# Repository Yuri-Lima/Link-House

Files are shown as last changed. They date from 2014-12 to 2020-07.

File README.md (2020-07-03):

<!-- Headings --> <!-- Strong --> <!-- Italics --> <!-- Blockquote --> <!-- Links --> <!-- UL --> <!-- OL --> <!-- Images --> <!-- Code Blocks --> <!-- Tables --> 
<!-- Task Lists -->

> # Homefi AX

### The project started in 2014. This project had the intention to created access for home automation to find an of family income population.
The Homefi module was created to be easily installed by users with low knowledge in home electronics. The unique skills  required the user wasi the connection of wires for the system to be installed. The Homefi project was cancelled around at 2016 after the launch of the Chinese module called Sonoff. This module basically does the same service as Homefi AX. **Web site:** [sonoff](https://sonoff.tech/) 

> ### Hardware

1. ESP8266 2.4Ghz board from espressif;
1. Solid States Relays;
1. 100 16v SMD Capacitors;
1. Hi-Link Imput 240Vac to 5Vdc/3w as Power Suply;
1. BC 846 Transistor;</li>
1. DHT11 as Temperature Sensor;
1. Varistor and Inductor as protection of the circuit;
1. General conectors.

> ### Software

1. Eagle to PCB;
1. Arduino IDE;
1. [Onlinegerberviewer](https://onlinegerberviewer.azurewebsites.net/)

> ### Software Main Language Used
* The Arduino IDE supports the languages C and C++ using special rules of code structuring. 
  The Arduino IDE supplies a software library from the Wiring project, which provides many common input and output procedures

> ### Protoypes Images

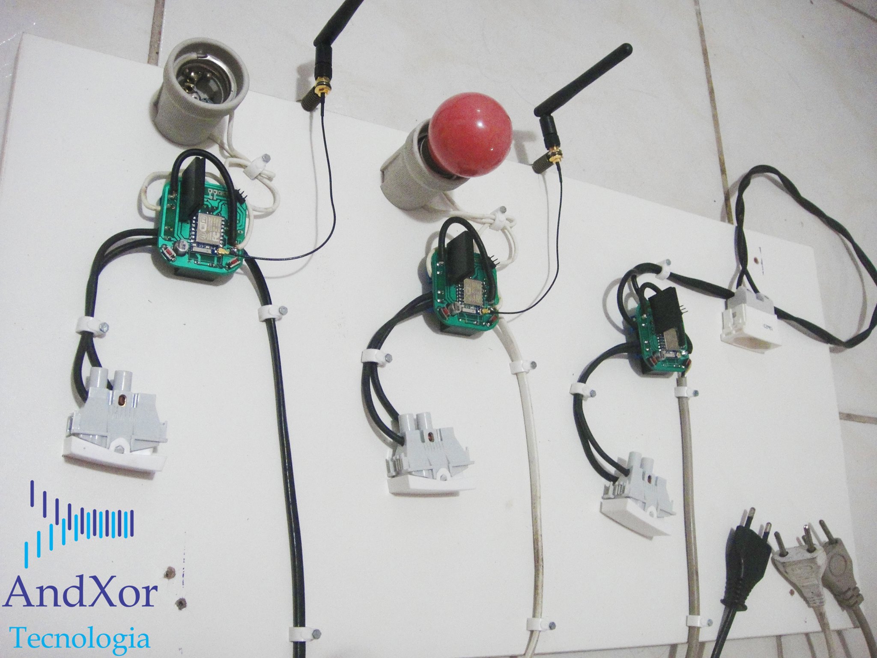
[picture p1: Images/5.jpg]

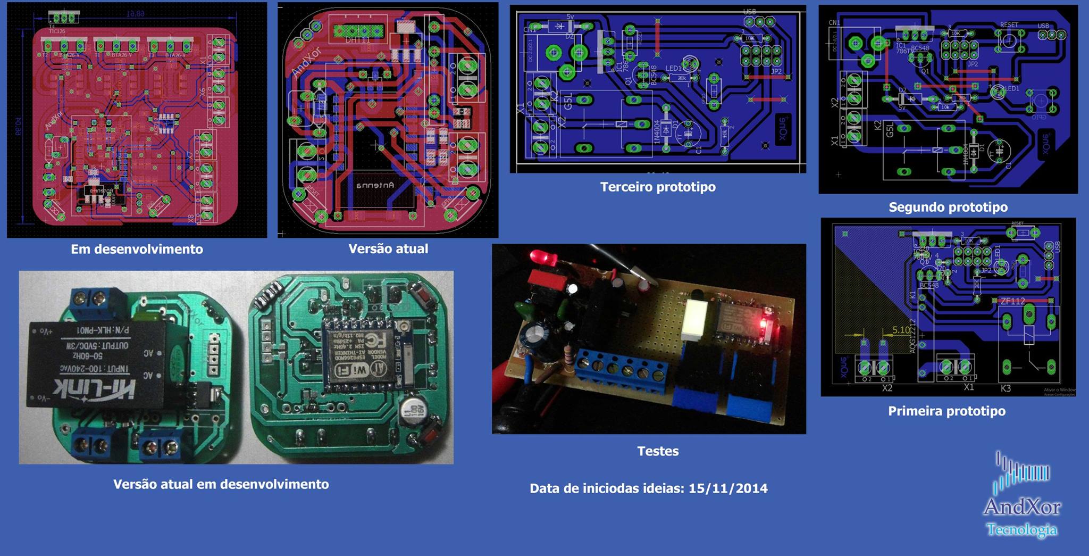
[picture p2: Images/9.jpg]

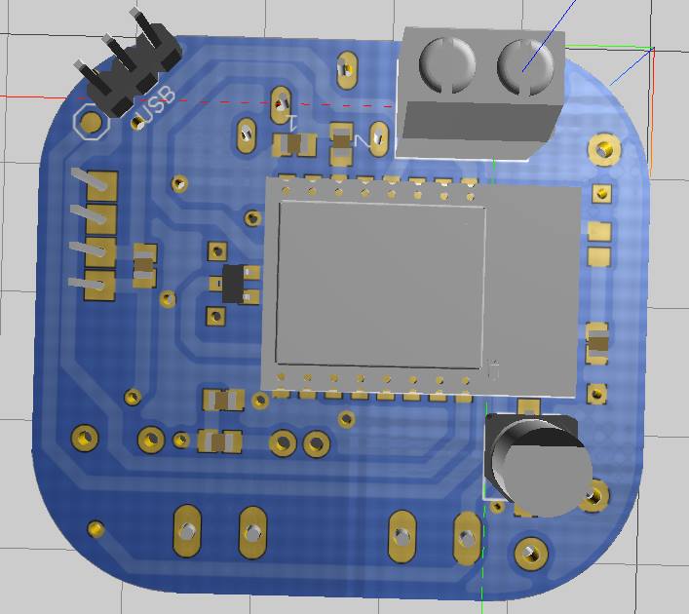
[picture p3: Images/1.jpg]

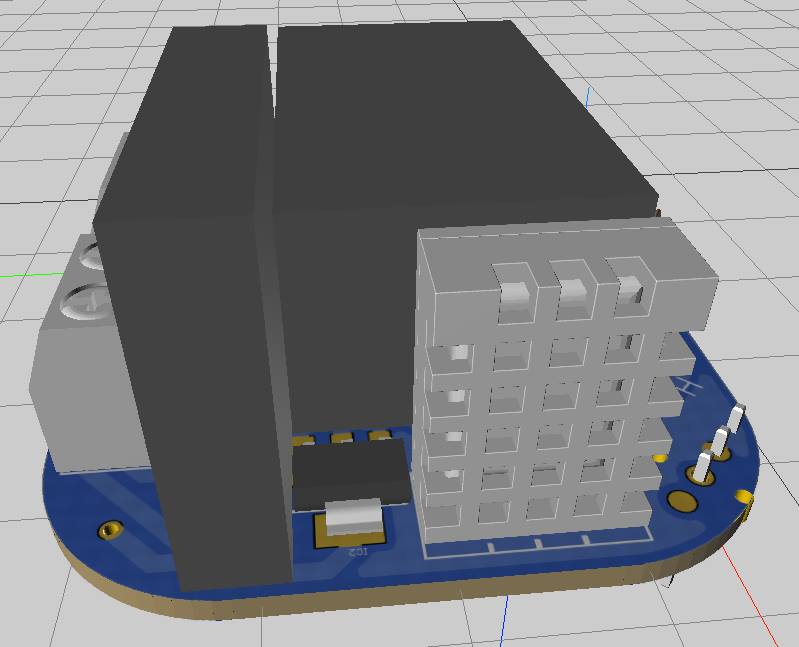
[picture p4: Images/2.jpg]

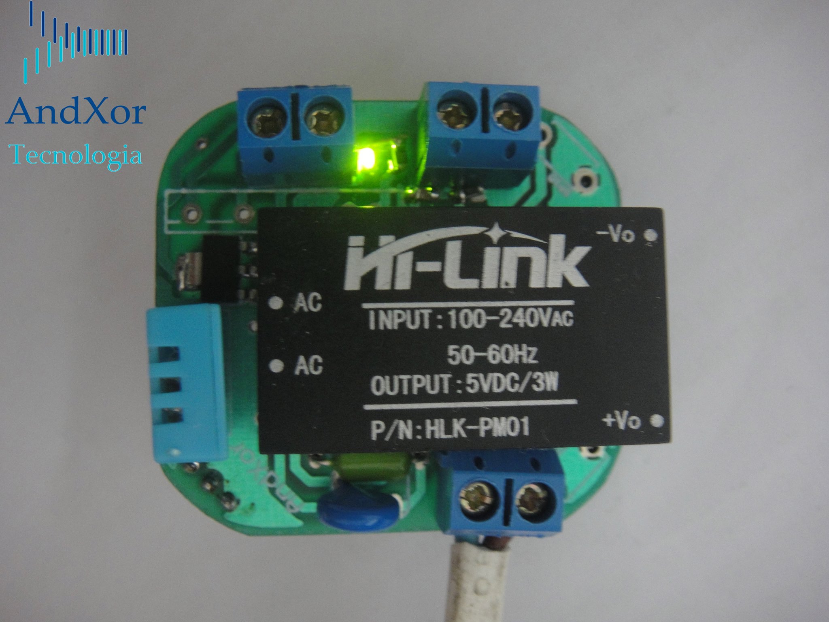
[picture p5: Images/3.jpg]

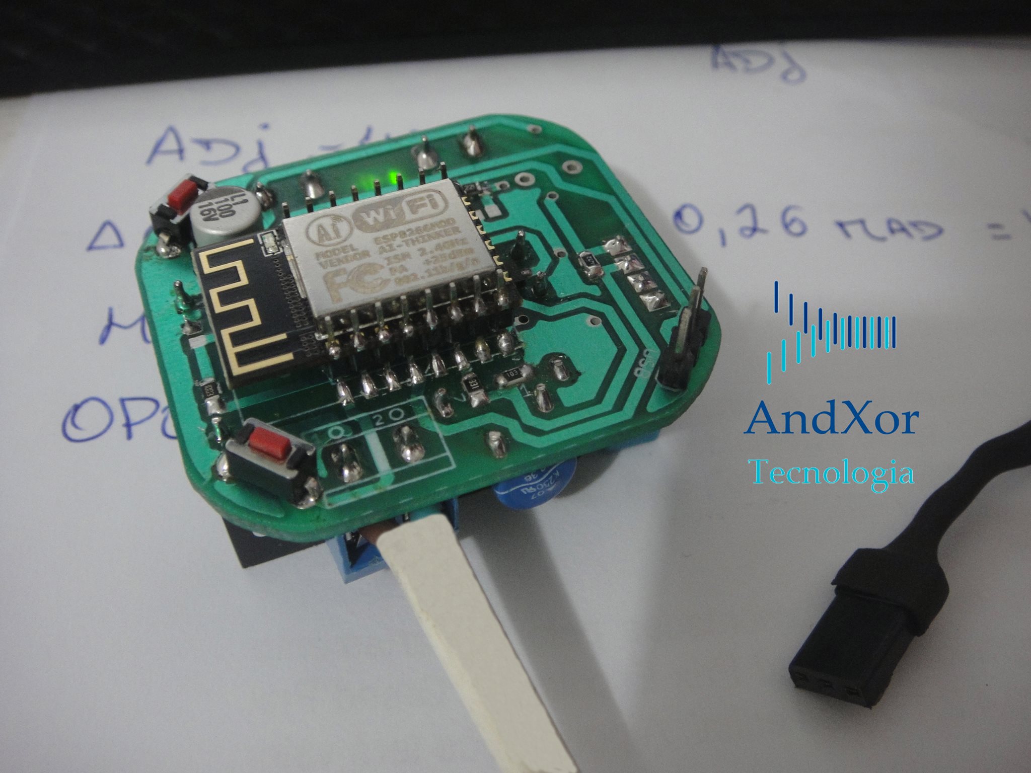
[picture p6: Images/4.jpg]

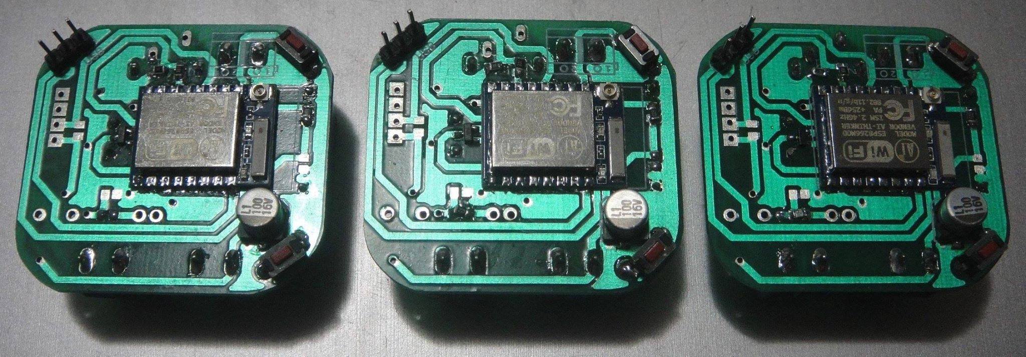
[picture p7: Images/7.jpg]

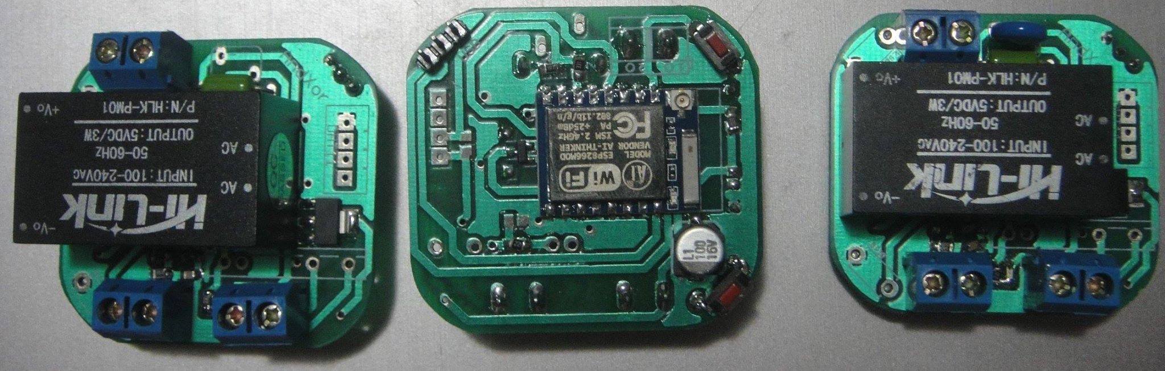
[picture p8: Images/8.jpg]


> ### Contact

> **Atention** If you go email me, please put as subject the name of the project, in this case: **(Homefi AX) Requests**

|  Name |  Email | Mobile  |
|---|---|---|
|  Yuri Lima | y.m.lima19@gmail.com  | +353 83 419.1605  |

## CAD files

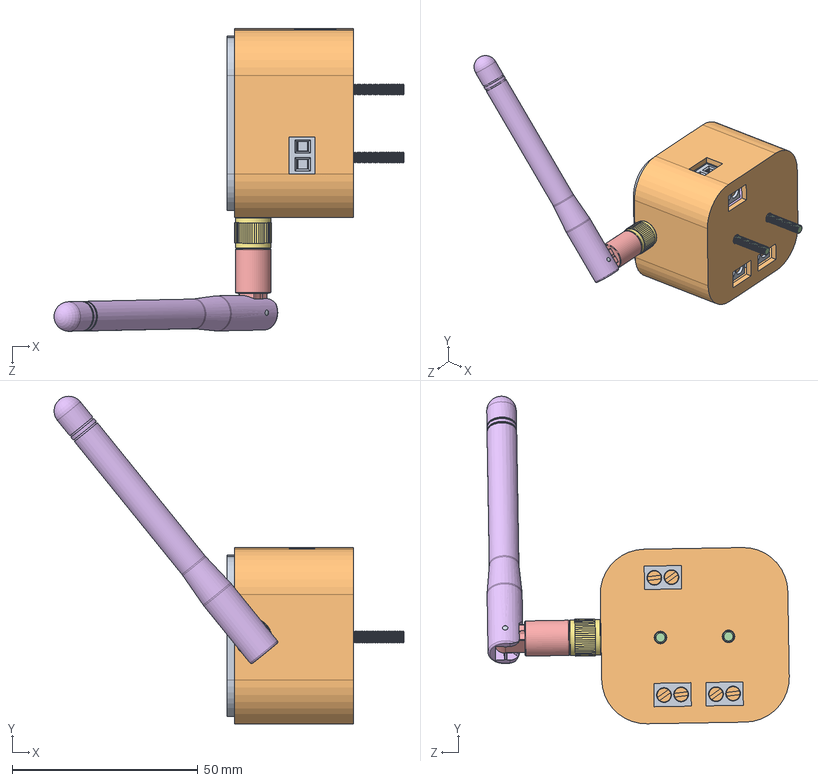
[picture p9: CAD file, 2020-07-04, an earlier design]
OLD Things/Case_Homefi/Montagem_final.SLDASM
94.2 x 88.2 x 81.5 mm
Case_Homefi_Orginal_Tampo
Case_Homefi_Orginal_Base
Case_Homefi
ESP8266-ESP07
DHT11
Hi_link
Push_Homefi x 2
Pinos x 3
TBlock2vias - KRE x 3
Parafusos x 6
PrensaFio x 12
countersunk flat head cross recess screw_iso x 2
Bottom_Radio_Antenna
Top_Radio_Antenna
Screw_Radio_Antenna
Insert_Radio_Antenna
Pin_Radio_Antenna x 2
Wire_Top_Radio_Antenna
Wire_Radio_Antenna

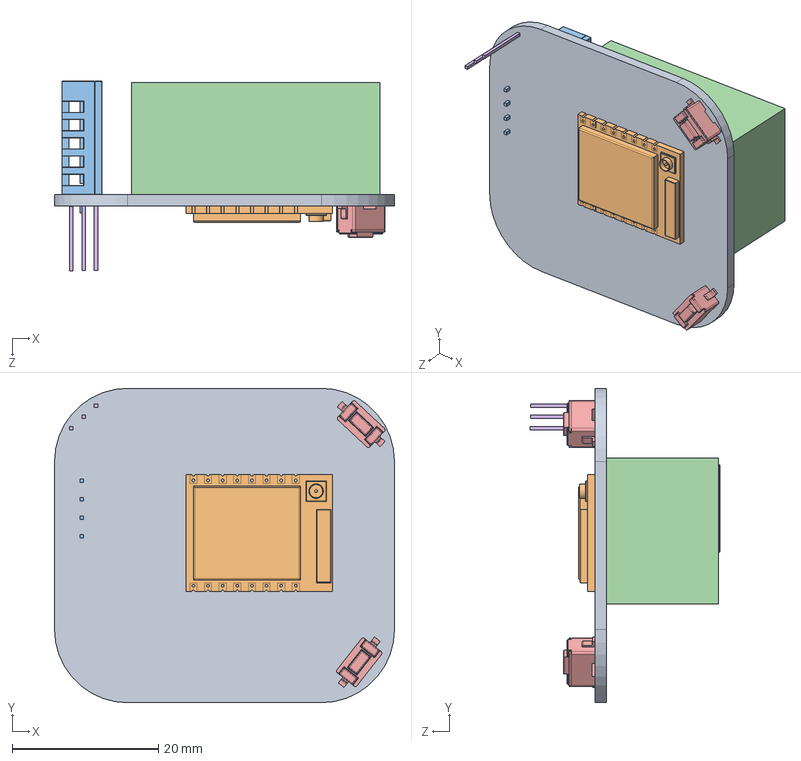
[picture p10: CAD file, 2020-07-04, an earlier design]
OLD Things/Case_Homefi/Componentes_Placa/Montagem_Modulo_Homefi.SLDASM
46.5 x 43.0 x 25.9 mm
Case_Homefi
ESP8266-ESP07
DHT11
Hi_link
Push_Homefi x 2
Pinos x 3

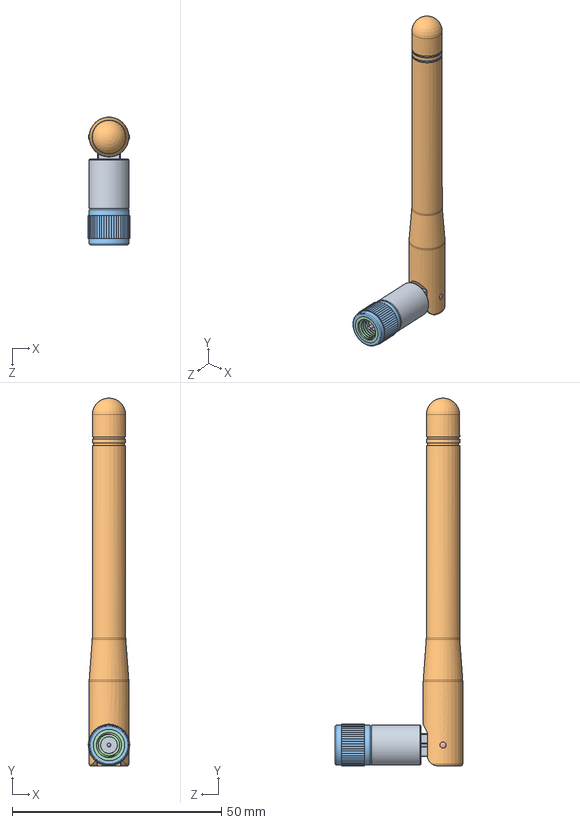
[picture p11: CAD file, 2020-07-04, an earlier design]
OLD Things/Case_Homefi/Componentes_Placa/antenna-9.snapshot.2/Antenna.SLDASM
9.99 x 87.9 x 30.5 mm
Bottom_Radio_Antenna
Top_Radio_Antenna
Screw_Radio_Antenna
Insert_Radio_Antenna
Pin_Radio_Antenna x 2
Wire_Top_Radio_Antenna
Wire_Radio_Antenna

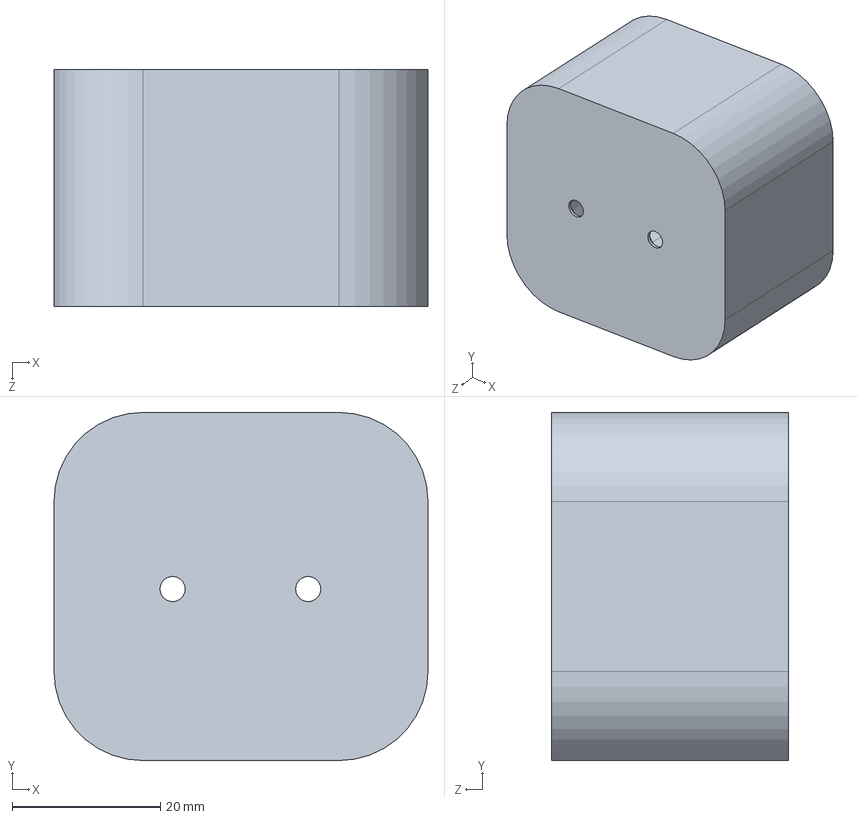
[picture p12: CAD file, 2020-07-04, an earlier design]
OLD Things/Case_Homefi/Case_Homefi_Orginal_Base.SLDPRT
50.5 x 47.0 x 32.0 mm

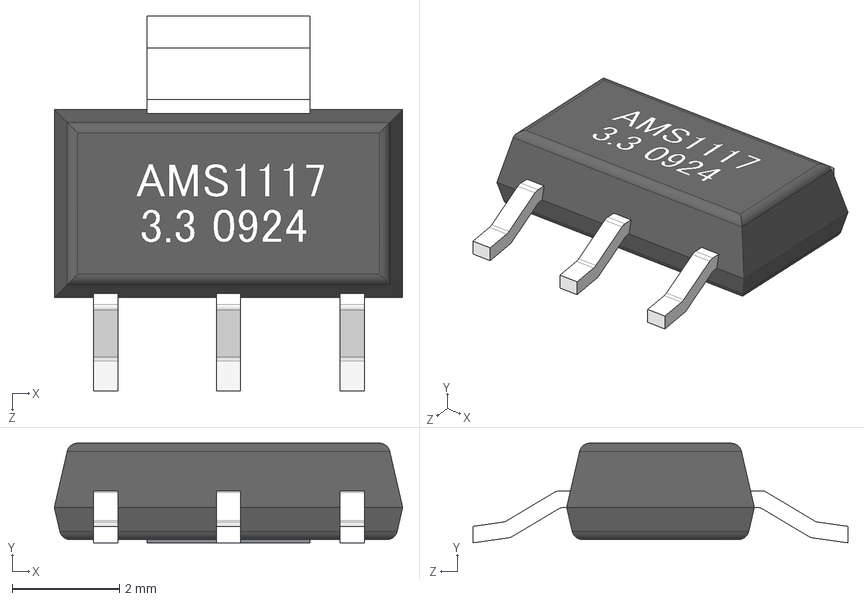
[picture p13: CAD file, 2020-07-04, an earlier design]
OLD Things/Case_Homefi/Componentes_Placa/ams1117-2.snapshot.1/AMS1117.STEP
6.50 x 1.86 x 7.00 mm

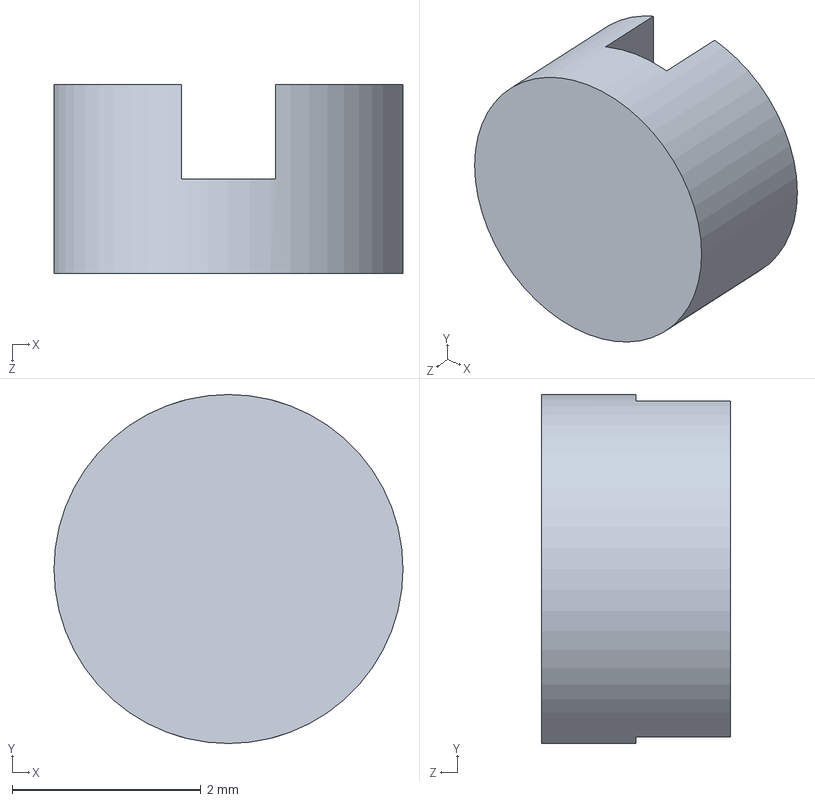
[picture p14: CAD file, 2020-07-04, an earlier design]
OLD Things/Case_Homefi/Componentes_Placa/borne-kre-2vias-1.snapshot.1/Tblock2vias/Parafusos.SLDPRT
3.70 x 3.70 x 2.00 mm

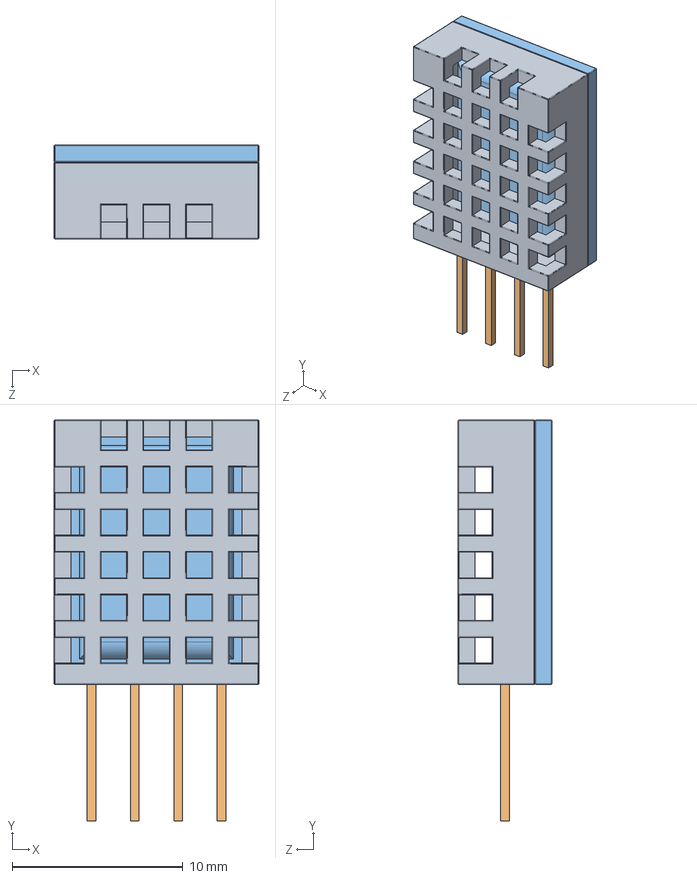
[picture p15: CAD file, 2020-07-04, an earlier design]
OLD Things/Case_Homefi/Componentes_Placa/dht11-1.snapshot.2/DHT11.STEP
12.0 x 23.5 x 5.50 mm

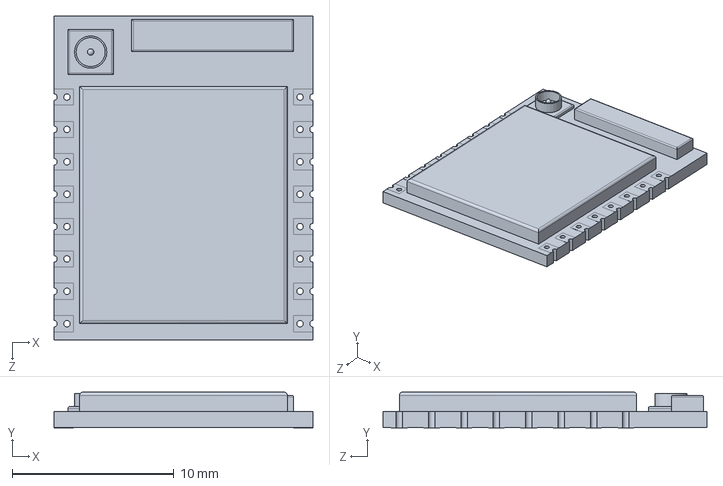
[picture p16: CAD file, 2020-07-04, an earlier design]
OLD Things/Case_Homefi/Componentes_Placa/esp8266-esp07-1.snapshot.1/ESP8266-ESP07.SLDPRT
16.0 x 2.21 x 20.0 mm

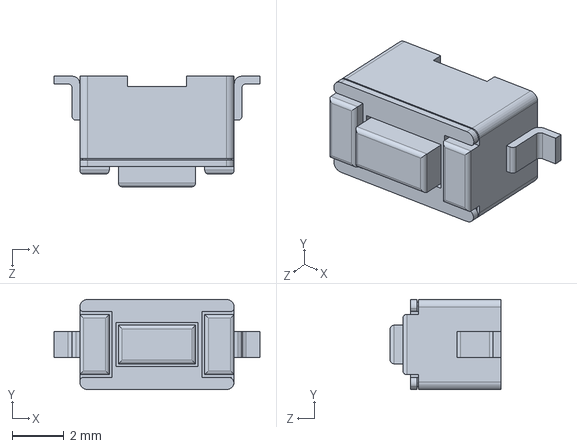
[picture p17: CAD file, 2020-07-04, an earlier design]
OLD Things/Case_Homefi/Componentes_Placa/momentary-reset-switch-smd-push-button-1.snapshot.1/Push_Homefi.SLDPRT
8.00 x 3.50 x 4.30 mm

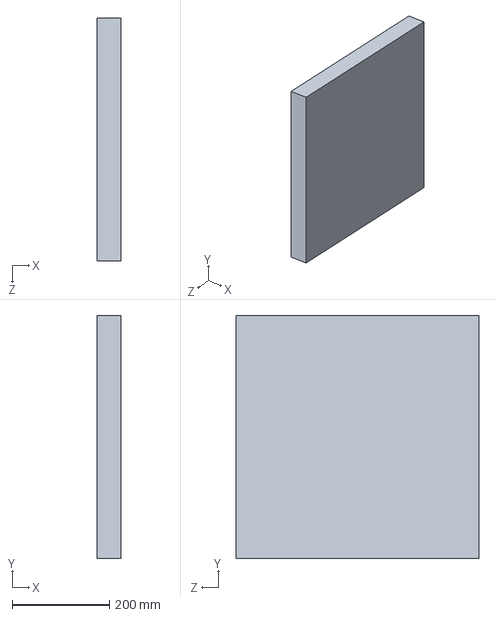
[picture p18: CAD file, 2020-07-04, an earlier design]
OLD Things/Case_Homefi/Componentes_Placa/Parede.SLDPRT
50.0 x 500.0 x 500.0 mm

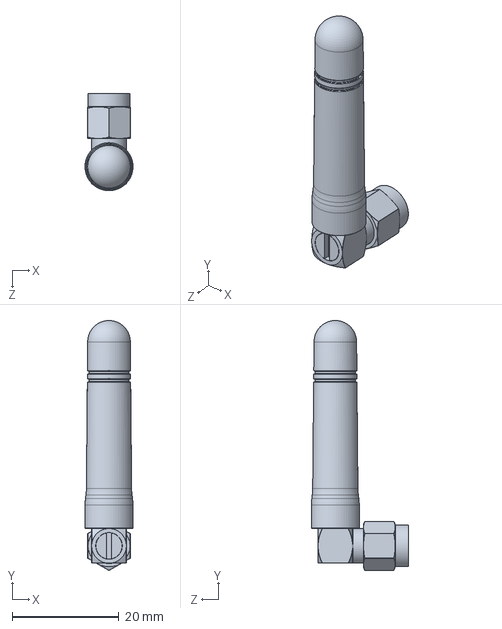
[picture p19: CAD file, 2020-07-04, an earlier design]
OLD Things/Case_Homefi/Componentes_Placa/sma-gsm-antenna-1.snapshot.2/User Library-SMA_AntennaR.SLDPRT
9.00 x 46.9 x 18.2 mm

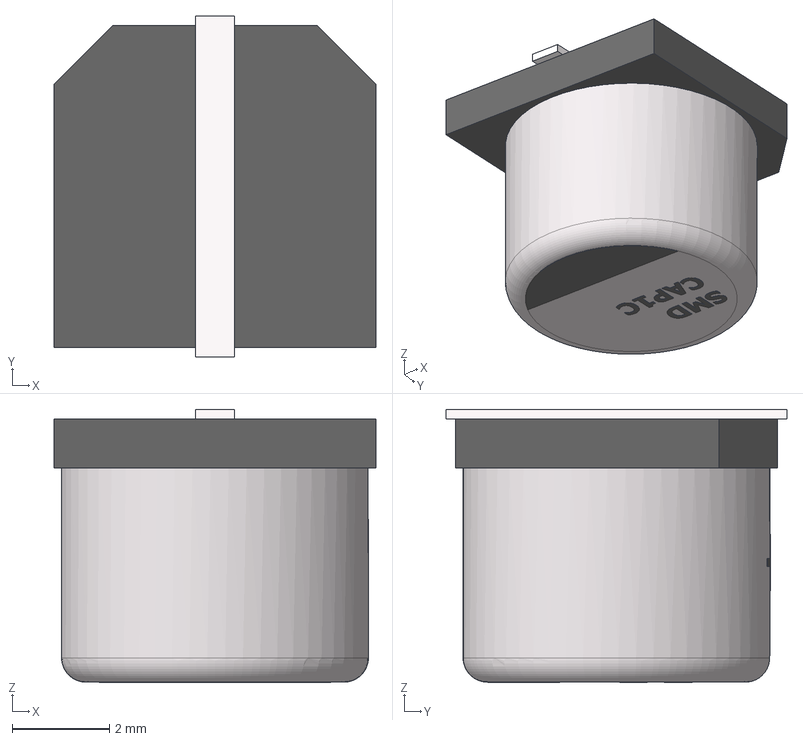
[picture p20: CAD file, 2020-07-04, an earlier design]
OLD Things/Case_Homefi/Componentes_Placa/smd-capacitor-1.snapshot.1/SMD_ELKO_6,3x5,8.stp
6.60 x 7.00 x 5.61 mm

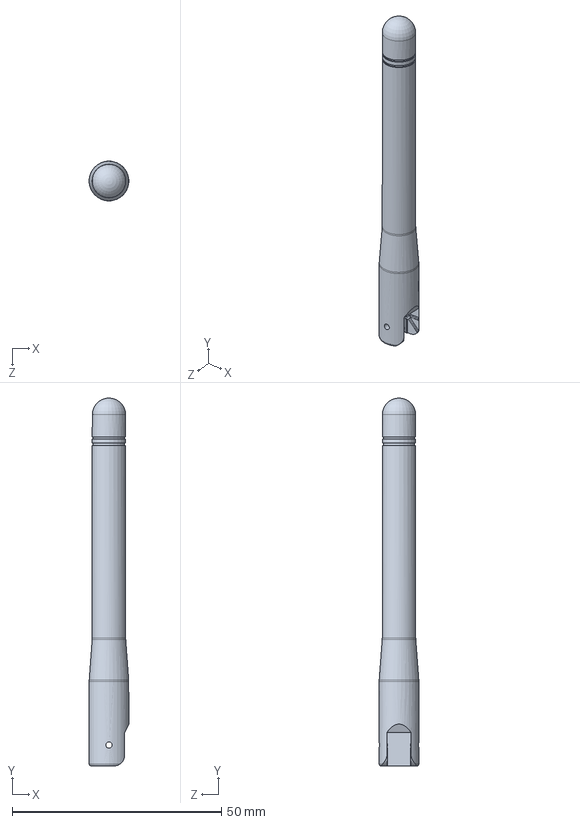
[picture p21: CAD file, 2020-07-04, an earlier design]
OLD Things/Case_Homefi/Componentes_Placa/antenna-9.snapshot.2/Top_Radio_Antenna.SLDPRT
9.47 x 87.9 x 9.50 mm

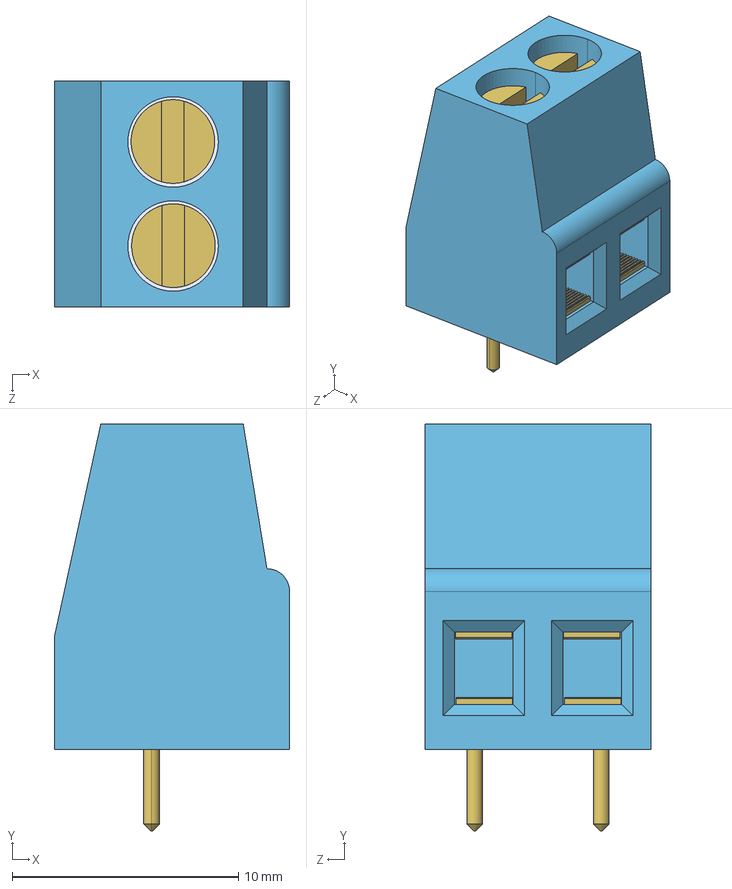
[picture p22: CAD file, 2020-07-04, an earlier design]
OLD Things/Case_Homefi/Componentes_Placa/borne-kre-2vias-1.snapshot.1/Tblock2vias/TBlock2vias - KRE.STEP
10.4 x 18.0 x 10.0 mm
TBlock2vias - KRE
Parafusos x 2
PrensaFio x 4

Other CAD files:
OLD Things/Case_Homefi/Componentes_Placa/momentary-reset-switch-smd-push-button-1.snapshot.1/Pulsador.stp
OLD Things/Case_Homefi/Componentes_Placa/Pinos.SLDPRT
OLD Things/Case_Homefi/Case_Homefi.SLDPRT
OLD Things/Case_Homefi/Componentes_Placa/antenna-9.snapshot.2/Wire_Top_Radio_Antenna.SLDPRT
OLD Things/Case_Homefi/Case_Homefi_Orginal.SLDPRT
OLD Things/Case_Homefi/Case_Homefi_Orginal_Tampo.SLDPRT
OLD Things/Case_Homefi/Componentes_Placa/Hi_link.SLDPRT
OLD Things/Case_Homefi/Componentes_Placa/ams1117-2.snapshot.1/AMS1117.SLDPRT
OLD Things/Case_Homefi/Componentes_Placa/antenna-9.snapshot.2/Bottom_Radio_Antenna.SLDPRT
OLD Things/Case_Homefi/Componentes_Placa/antenna-9.snapshot.2/Insert_Radio_Antenna.SLDPRT
OLD Things/Case_Homefi/Componentes_Placa/antenna-9.snapshot.2/Pin_Radio_Antenna.SLDPRT
OLD Things/Case_Homefi/Componentes_Placa/antenna-9.snapshot.2/Screw_Radio_Antenna.SLDPRT
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

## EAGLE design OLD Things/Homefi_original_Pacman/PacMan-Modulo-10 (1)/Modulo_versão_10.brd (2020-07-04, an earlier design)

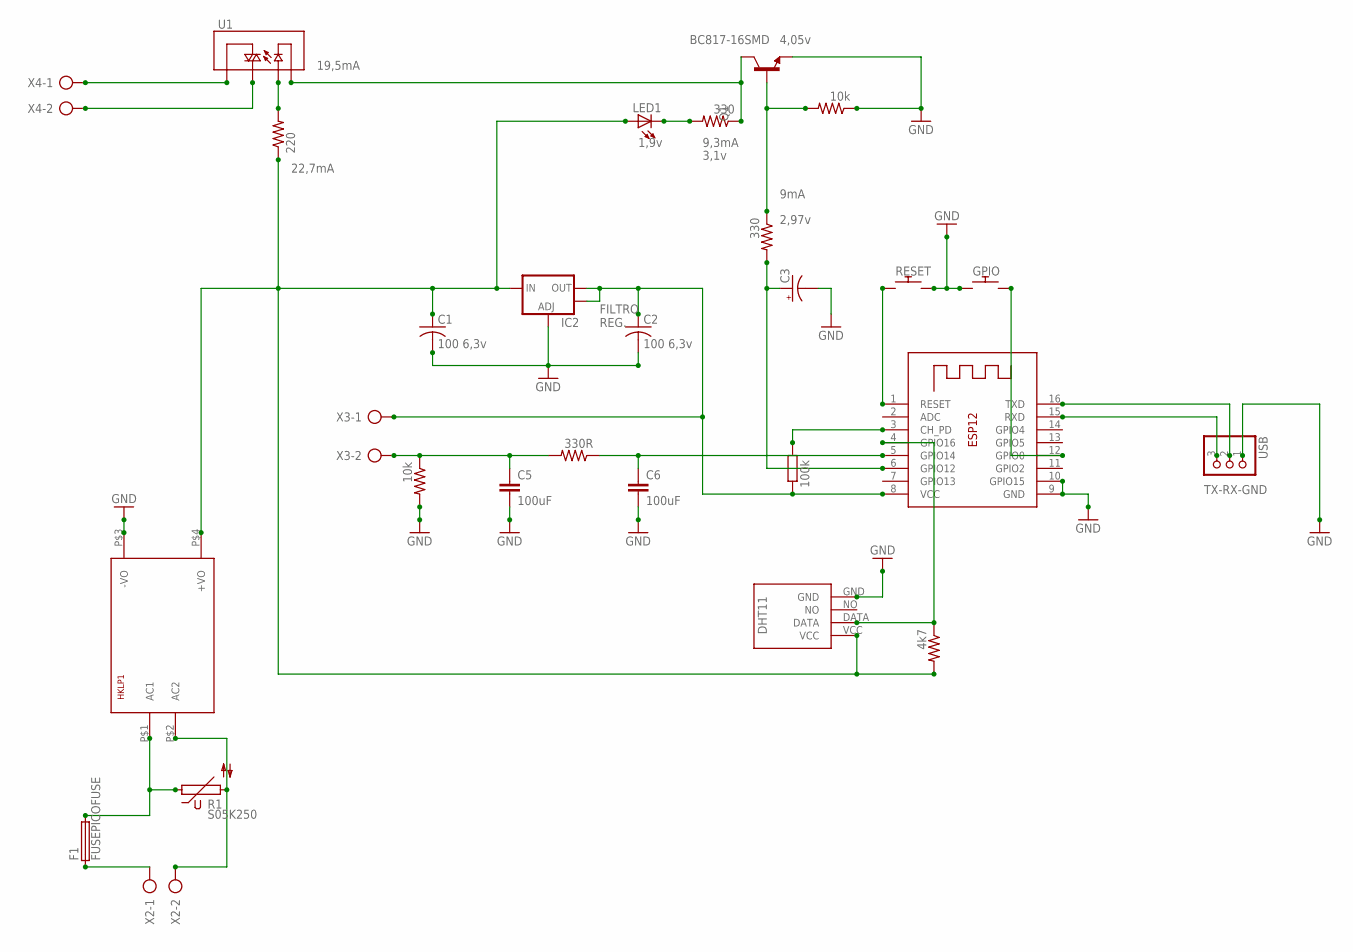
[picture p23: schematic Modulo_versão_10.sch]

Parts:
1, 2: 10k; M0805
3: 100k; M0805
4: 330R; M0805
5, 7: 330; M0805
6: 220; M0805
8: 4k7; M0805
C1, C2: 100 6,3v; C0805
C3: CPOL-US153CLV-0605; 153CLV-0605
C5, C6: 100uF; C0805
F1: FUSEPICOFUSE; PICOFUSE
GPIO: GPIO; TACT_PANA-EVQ
HKLP1: HKLPM01
IC2: V_REG_LM1117SOT223; SOT223
LED1: LEDCHIPLED_0805; CHIPLED_0805
Q1: BC817-16SMD; SOT23-BEC
R1: S05K250
RESET: RESET; TACT_PANA-EVQ
U1: RELAY-SOLIDSTATEPTH; RELAY-S108T02
U$1: DHT11-PION.
USB: PINHD-1X3; 1X03
X2, X3, X4: AK500/2
X5: ESP-12

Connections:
2N3904: 5.1, Q1.C, U1.4 (-)
5V: 6.1, 8.2, C1.1, HKLP1.P$4 (+VO), IC2.3 (IN), LED1.A, U$1.VCC
GND: 1.1, 2.2, C1.2, C2.2, C3.-, C5.2, C6.2, GPIO.P$1, HKLP1.P$3 (-VO), IC2.1 (ADJ), Q1.E, RESET.P$2, U$1.GND, USB.1, X5.9 (GND), X5.10 (GPIO15)
unnamed: 3.1, C2.1, IC2.2 (OUT), IC2.4 (OUT), X3.1, X5.8 (VCC)
unnamed: 5.2, LED1.C
unnamed: U1.2 (T2), X4.2
unnamed: U1.1 (T1), X4.1
unnamed: USB.3, X5.15 (RXD)
unnamed: RESET.P$1, X5.1 (RESET)
unnamed: F1.1, X2.1
unnamed: 1.2, 7.1, Q1.B
unnamed: F1.2, HKLP1.P$1 (AC1), R1.1
unnamed: 4.1, C6.1, X5.5 (GPIO14)
unnamed: 6.2, U1.3 (+)
unnamed: 2.1, 4.2, C5.1, X3.2
unnamed: 3.2, X5.3 (CH_PD)
unnamed: 7.2, C3.+, X5.6 (GPIO12)
unnamed: HKLP1.P$2 (AC2), R1.2, X2.2
unnamed: 8.1, U$1.DATA, X5.4 (GPIO16)
unnamed: GPIO.P$2, X5.12 (GPIO0)
unnamed: USB.2, X5.16 (TXD)

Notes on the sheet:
FILTRO REG.
TX-RX-GND
9mA
1,9v
9,3mA
22,7mA
19,5mA
2,97v
3,1v
4,05v

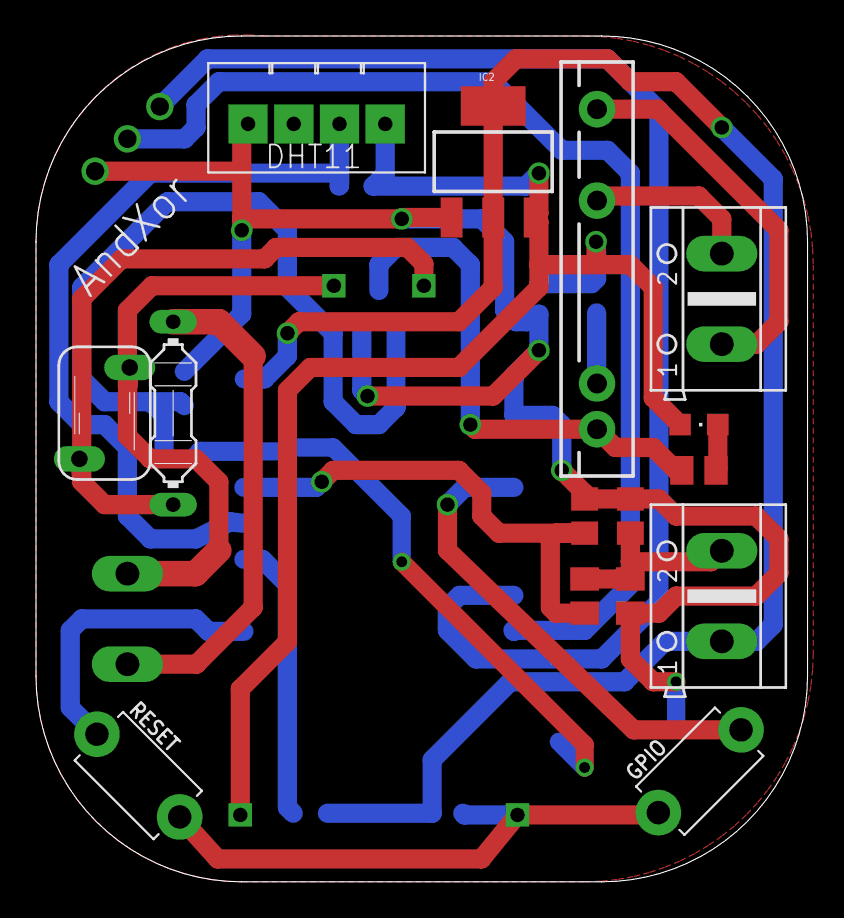
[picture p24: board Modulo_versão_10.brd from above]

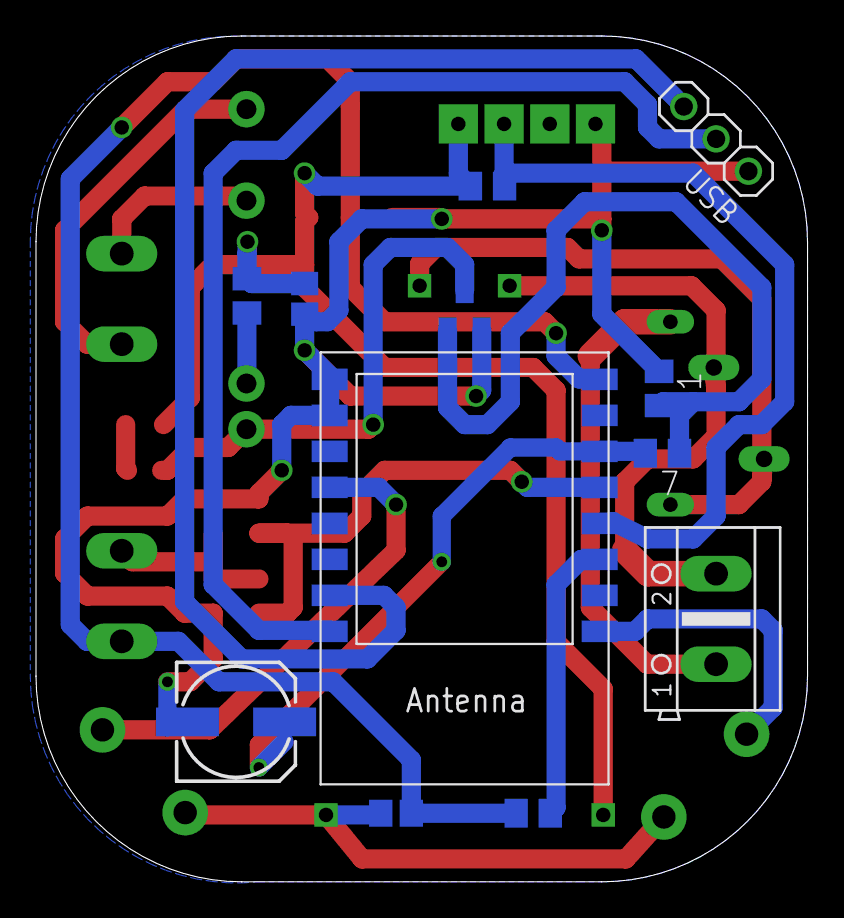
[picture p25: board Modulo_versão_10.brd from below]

Board: 2 copper layers, 42.9 x 47.0 mm, 28 parts (12 on the bottom side), 21 nets.

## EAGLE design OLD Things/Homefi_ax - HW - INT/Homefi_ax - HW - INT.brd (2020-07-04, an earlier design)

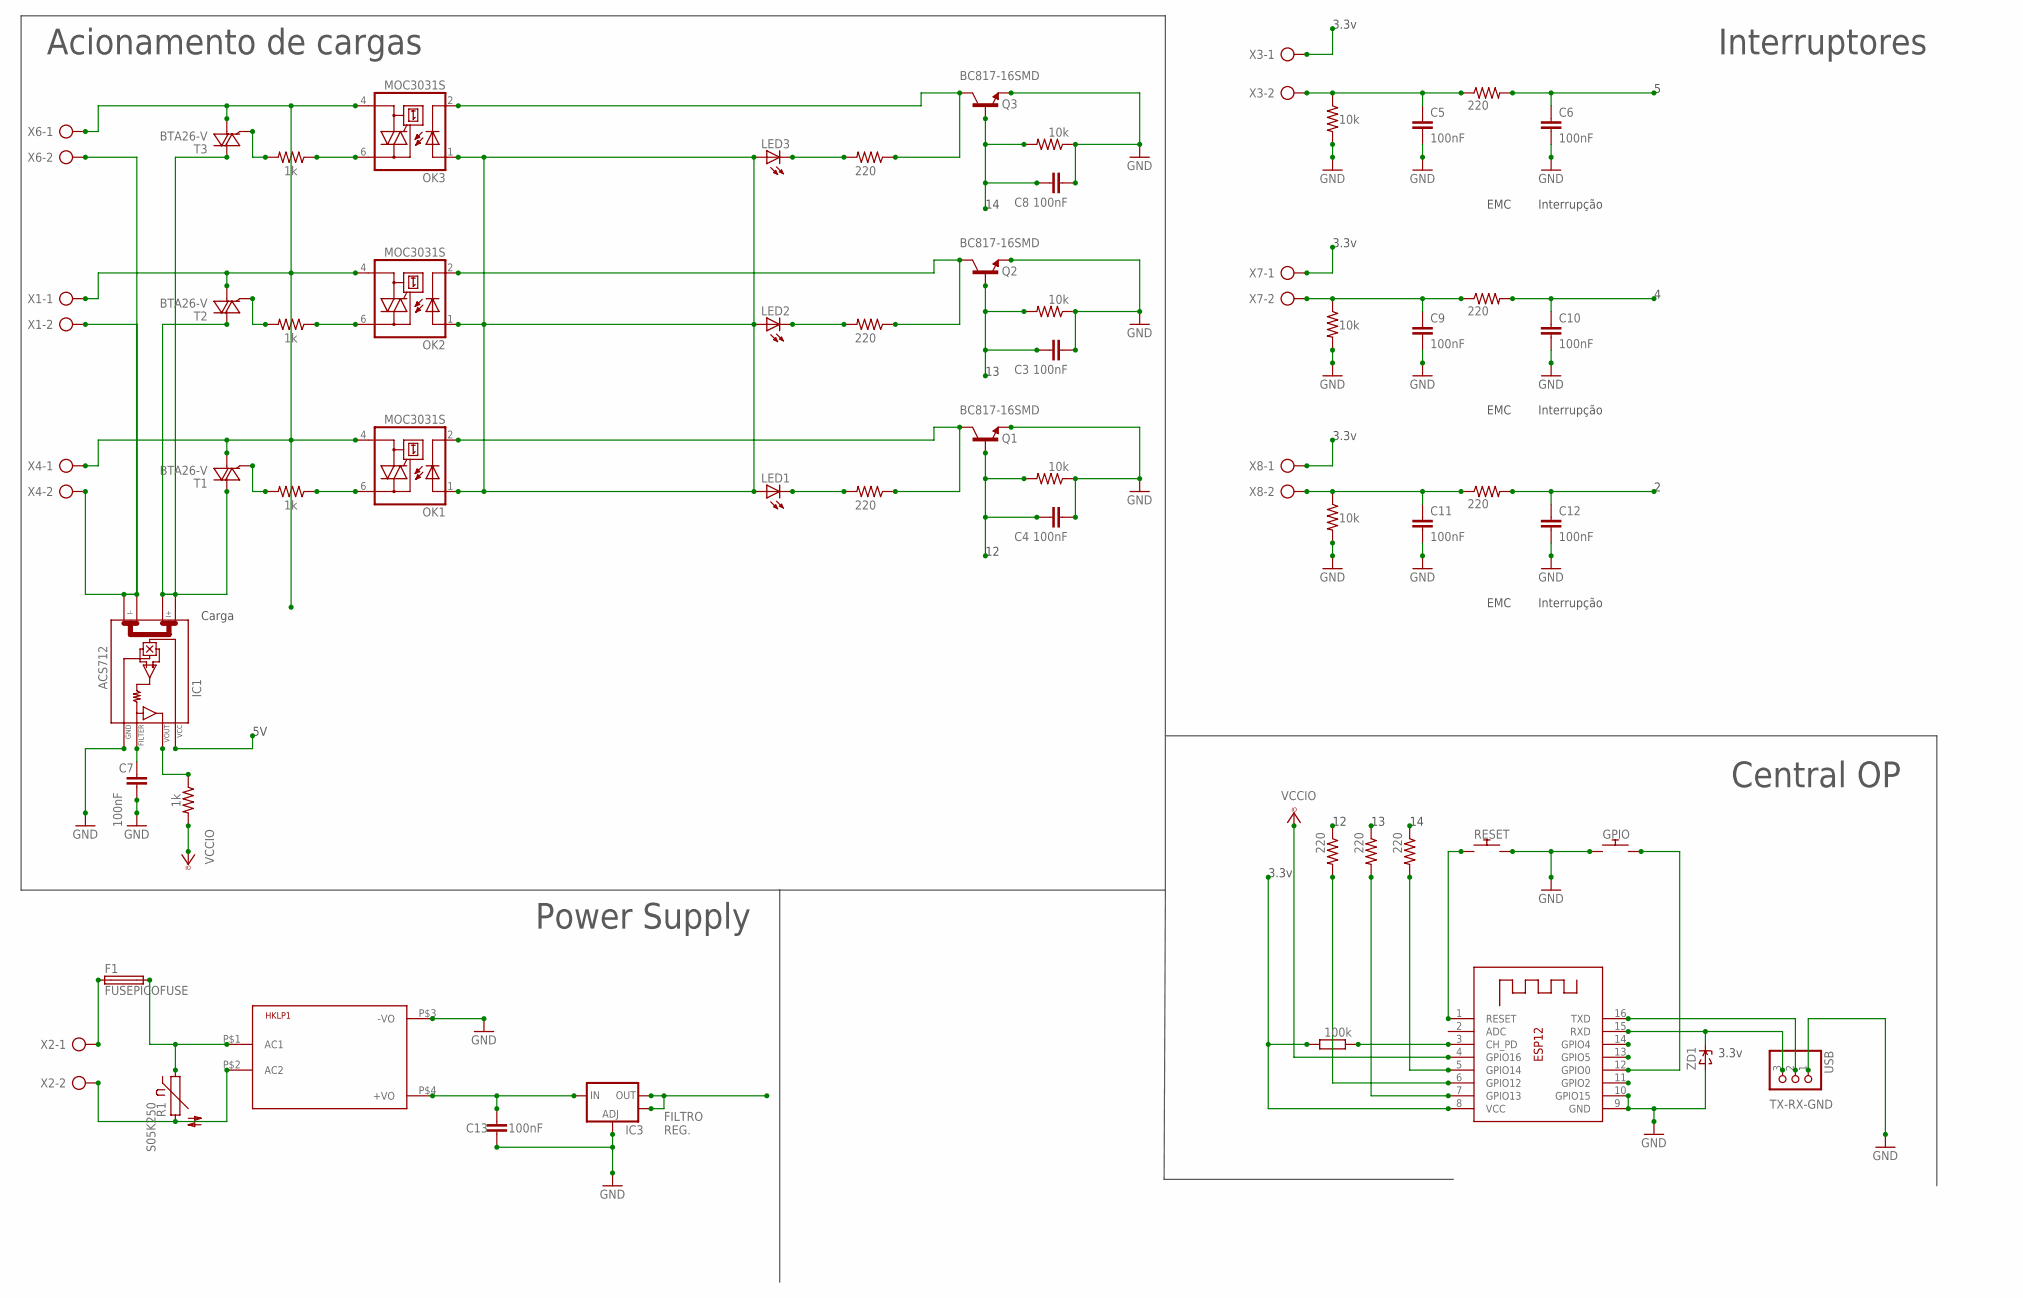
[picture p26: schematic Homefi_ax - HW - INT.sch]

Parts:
1, 2, 9, 11, 15, 17: 10k; M0805
3: 100k; M0805
4, 8, 19, 20: 1k; M0805
5, 6, 7, 10, 12, 13, 14, 16, 18: 220; M0805
C3, C4, C5, C6, C7, C8, C9, C10, C11, C12, C13: 100nF; C0805
F1: FUSEPICOFUSE; PICOFUSE
GPIO: GPIO; TACT_PANA-EVQ
HKLP1: HKLPM01
IC1: ACS712; SO08
IC3: V_REG_LM1117SOT223; SOT223
LED1, LED2, LED3: LEDCHIPLED_0805; CHIPLED_0805
OK1, OK2, OK3: MOC3031S; DIL6-SMD
Q1, Q2, Q3: BC817-16SMD; SOT23-BEC
R1: S05K250
RESET: RESET; TACT_PANA-EVQ
T1, T2, T3: BTA26-V; TOP3S-1
USB: PINHD-1X3; 1X03
X1, X2, X3, X4, X6, X7, X8: AK500/2
X5: ESP-12
ZD1: ZENERSOD-123; SOD-123

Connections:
2: 18.2, C12.1, X5.11 (GPIO2)
2N1: 10.1, OK2.2 (C), Q2.C
2N2: 12.1, OK3.2 (C), Q3.C
2N3904: 5.1, OK1.2 (C), Q1.C
3.3V: 3.2, IC3.2 (OUT), IC3.4 (OUT), X3.1, X5.8 (VCC), X7.1, X8.1
4: 16.2, C10.1, X5.14 (GPIO4)
5: 6.2, C6.1, X5.13 (GPIO5)
5V: C13.2, HKLP1.P$4 (+VO), IC1.8 (VCC), IC3.3 (IN), LED1.A, LED2.A, LED3.A, OK1.1 (A), OK2.1 (A), OK3.1 (A)
12: 1.2, 7.1, C4.1, Q1.B
13: 9.2, 13.1, C3.1, Q2.B
14: 11.2, 14.1, C8.1, Q3.B
220V: F1.2, HKLP1.P$1 (AC1), OK1.4 (A1), OK2.4 (A1), OK3.4 (A1), R1.1, T1.A1, T2.A1, T3.A1, X1.1, X4.1, X6.1
220V2: F1.1, X2.1
GND: 1.1, 2.2, 9.1, 11.1, 15.2, 17.2, C3.2, C4.2, C5.2, C6.2, C7.1, C8.2, C9.2, C10.2, C11.2, C12.2, C13.1, GPIO.P$1, HKLP1.P$3 (-VO), IC1.5 (GND), IC3.1 (ADJ), Q1.E, Q2.E, Q3.E, RESET.P$2, USB.1, X5.9 (GND), X5.10 (GPIO15), ZD1.A
unnamed: 13.2, X5.7 (GPIO13)
unnamed: 14.2, X5.5 (GPIO14)
unnamed: 5.2, LED1.C
unnamed: 20.1, OK1.6 (A2)
unnamed: RESET.P$1, X5.1 (RESET)
unnamed: C7.2, IC1.6 (FILTER)
unnamed: 8.1, IC1.7 (VOUT)
unnamed: USB.3, X5.15 (RXD), ZD1.C
unnamed: GPIO.P$2, X5.12 (GPIO0)
unnamed: 19.1, OK2.6 (A2)
unnamed: 4.1, OK3.6 (A2)
unnamed: 10.2, LED2.C
unnamed: IC1.3 (I-_0), IC1.4 (I-_1), X1.2, X4.2, X6.2
unnamed: 15.1, 16.1, C9.1, X7.2
unnamed: 2.1, 6.1, C5.1, X3.2
unnamed: 3.1, X5.3 (CH_PD)
unnamed: 7.2, X5.6 (GPIO12)
unnamed: HKLP1.P$2 (AC2), R1.2, X2.2
unnamed: 12.2, LED3.C
unnamed: 17.1, 18.1, C11.1, X8.2
unnamed: USB.2, X5.16 (TXD)
unnamed: 20.2, T1.G
unnamed: 19.2, T2.G
unnamed: 4.2, T3.G
unnamed: IC1.1 (I+_0), IC1.2 (I+_1), T1.A2, T2.A2, T3.A2
VCCIO: 8.2, X5.4 (GPIO16)

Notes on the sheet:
TX-RX-GND
3.3v
EMC
Interrupção
Carga
FILTRO REG.
Power Supply
Central OP
Interruptores
Acionamento de cargas

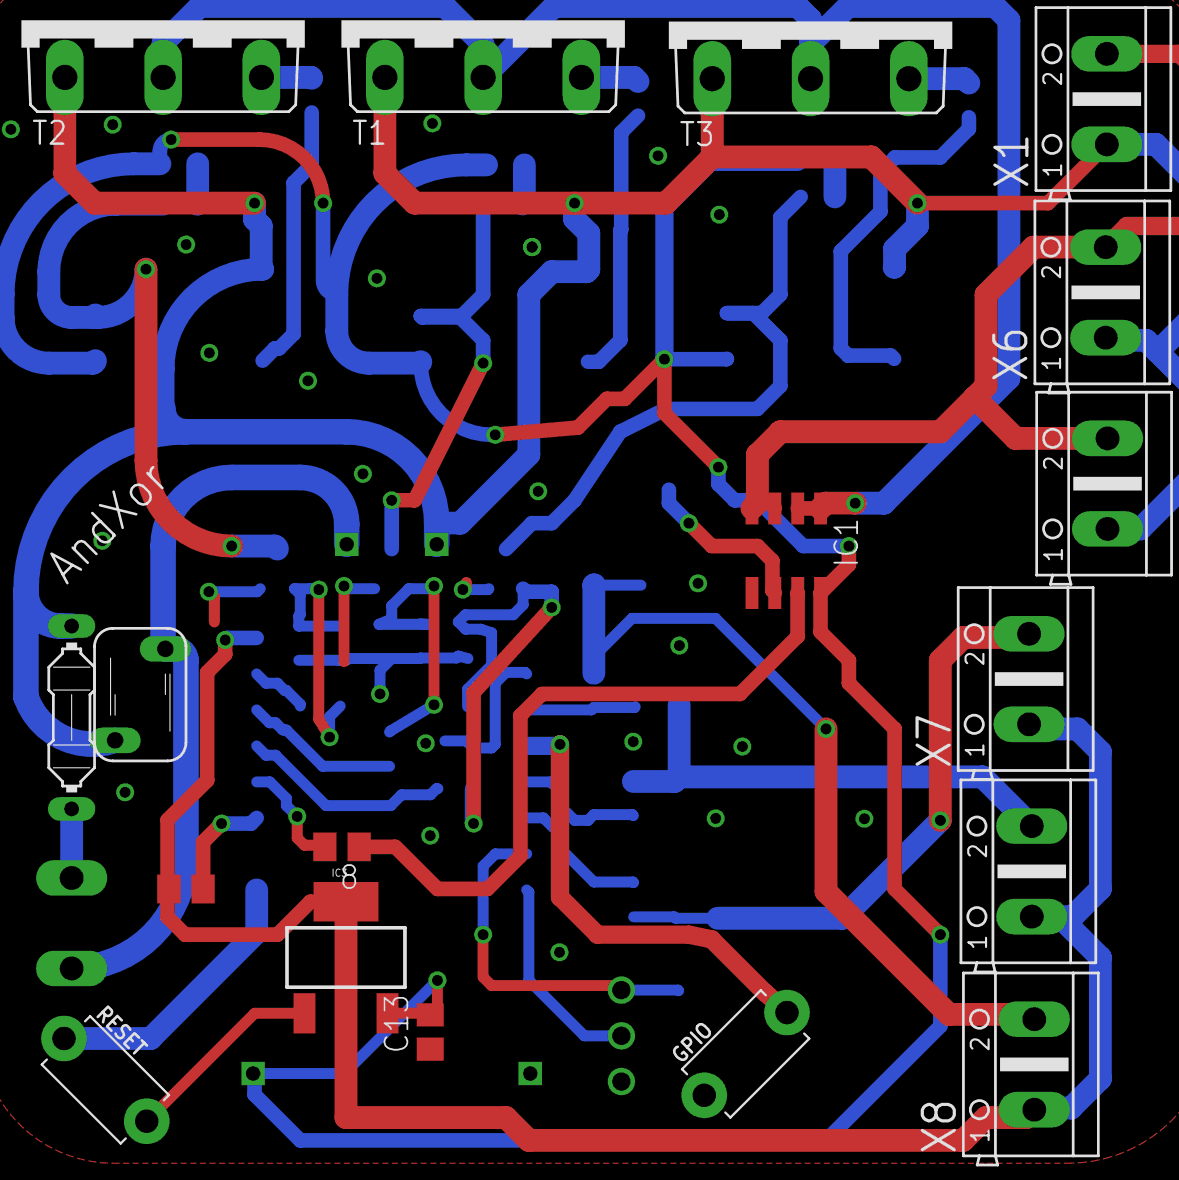
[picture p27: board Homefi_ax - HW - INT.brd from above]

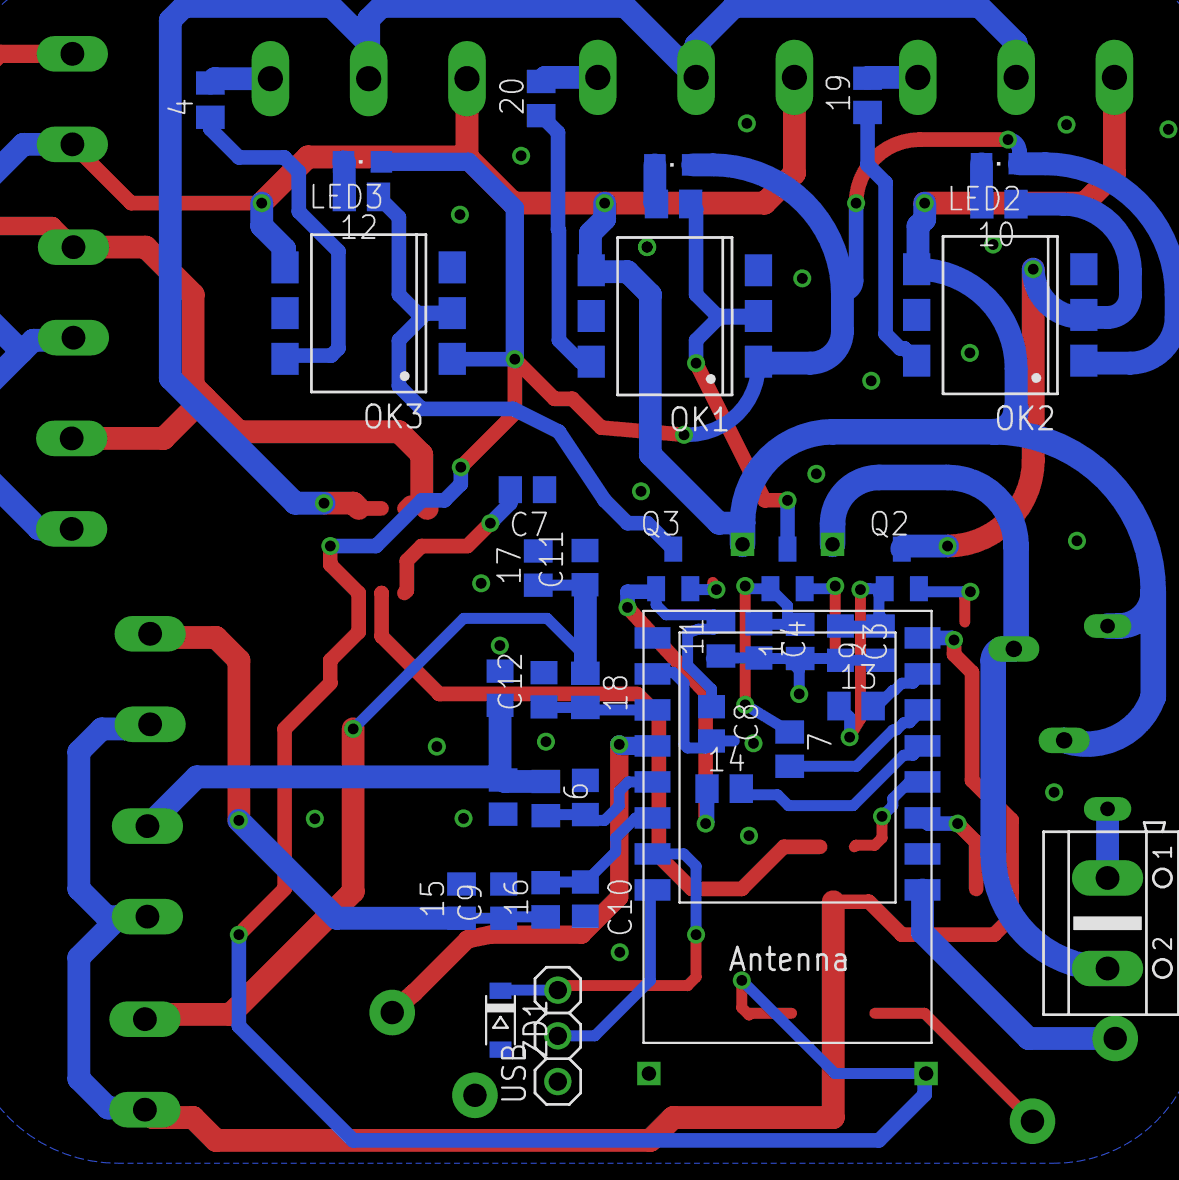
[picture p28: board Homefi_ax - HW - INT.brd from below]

Board: 2 copper layers, 60 parts (41 on the bottom side), 40 nets.

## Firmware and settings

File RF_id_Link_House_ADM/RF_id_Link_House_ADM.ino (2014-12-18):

//Inclusão de bibliotecas
#include "SoftwareSerial.h"
#include <SD.h>
#define botao 2
SoftwareSerial RFID(12, 11); 

//Variaceis Strigs e Char-------------------------------------------------------
String RFleitura="",cartaogravado="",opcao="",Leite="";
char leicartao, leiturabutao,funcaolida;
char lei[17]={};
char valorlido[17]={};

//Classe da biblioteca Sd que ajuda na manipulação de arquivos------------------
//Classe File
File arquivo;
//Condicao para ir para o loop se o cartao sd estiver ok
byte ok;

//Inicio da função Setup--------------------------------------------------------
void setup(){ 
  pinMode(botao,INPUT_PULLUP);
  Serial.begin(9600);
  RFID.begin(9600);
   
  //Não vai pro loop, se não tiver cartão----------------------------------------
  ok=1;
  if(!SD.begin(4)){
    Serial.println("Erro ao iniciar cartao SD");
    Serial.println("Diagnostico: Sem cartao SD");
    ok=1;
    return;
  }
  else{
    Serial.println("Cartao SD Iniciado");
  }
  Serial.println("Passe o cartao de acesso!");
}// Fecha Setup----------------------------------------------------------------

void Cadastro(){
  Serial.println("Passe o cartao novo.");
  while(1){
    if(RFID.available()){
      for(char i=0;i<=15;i++){
        lei[i]=RFID.read();
        delay(10);
      }
      if (sizeof(lei)>=15){
        for(char i=1; i<=13;i++){
          Leite=lei;
        }
        arquivo=SD.open("cadastro.txt",FILE_WRITE);
        if(arquivo){
          arquivo.println(Leite.substring(1,13));
          Serial.print("Cartao salvo com sucesso!: ");
          for(char i=1; i<=13;i++){
            Serial.print(lei[i]);
          }
          //Temos que fechar o arquivo o mais cedo possivel para liberar o ponteiro do arquivo     
          arquivo.close();
        }
        else{
          Serial.println("Erro ao abrir o arquivo para escrita");
        }
      }
    }//Fecha If RFID available*/
  }//Fecha While flag
 
}//Fecha Funcao Cadastro------------------------------------------------------

void Desabilitar(){
  SD.remove("cadastro.txt");
  if(!SD.exists("cadastro.txt")){
    Serial.println("Cartoes apagados com sucesso");
    cartaogravado="";
    return;
  }
  else{
    Serial.println("Erro ao apagar os cartoes, tente novamente!");
  } 
}//Fecha Desabilitar-----------------------------------------------------------

void Ativos(){
 arquivo = SD.open("cadastro.txt",FILE_READ);
  if (arquivo) {
    Serial.println("Cartoes cadastrado: ");
    while (arquivo.available()) {
      Serial.write(arquivo.read());
    }
    arquivo.close();
  }
  else{
    Serial.println("Nenhum arquivo encontrado");
  }
}//Fecha Ativos------------------------------------------------------------------- 

void Menu(){
  
  if (digitalRead(botao)==HIGH) {
    //Entra no modo função
    Serial.println("Qual a funcao do menu voce deseja?");
    Serial.println();
    Serial.println("1 - Cadastro de novo cartao.");
    Serial.println();
    Serial.println("2 - Desabilitar cartao.");
    Serial.println();
    Serial.println("3 - Cartoes ativos.");
    Serial.println();
    delay(100);
  }//Fecha if HIGH-------------------------------------------------------------
  delay(10);
  //while(leiturabutao==HIGH){
    while (Serial.available()){
      funcaolida = Serial.read();
      switch (funcaolida) {
        case '1': Cadastro();
        //return;
        break;
        case '2': Desabilitar();
        //return;
        break;
        case '3': Ativos();
        //return;
        break;
        default: Serial.println("Funcao invalida");
        return;
      }//Fecha Switch funcaolida-------------------------------------------------
    }//Fecha While Serial--------------------------------------------------------
  //}//Fecha While HIGH------------------------------------------------------------
}//Fecha Leiturabotao()----------------------------------------------------------

void Verificar(){
 // Faz as comparações com o que esta gravado no SD e com o ponteiro char* cartoes[] 
  if ( RFleitura.substring(1,13).equals(cartaogravado.substring(0,12))
    || RFleitura.substring(1,13).equals(cartaogravado.substring(14,26))
    || RFleitura.substring(1,13).equals(cartaogravado.substring(28,40))
    || RFleitura.substring(1,13).equals(cartaogravado.substring(42,54))
    || RFleitura.substring(1,13).equals(cartaogravado.substring(56,68))
    || RFleitura.substring(1,13).equals(cartaogravado.substring(70,82))
    || RFleitura.substring(1,13).equals(cartaogravado.substring(84,96))
    || RFleitura.substring(1,13).equals(cartaogravado.substring(98,110))
    || RFleitura.substring(1,13).equals(cartaogravado.substring(112,124))
    || RFleitura.substring(1,13).equals(cartaogravado.substring(126,138))
    || RFleitura.substring(1,13).equals(cartaogravado.substring(140,152))
    || RFleitura.substring(1,13).equals(cartaogravado.substring(154,166))
    || RFleitura.substring(1,13).equals(cartaogravado.substring(168,180))
    || RFleitura.substring(1,13).equals(cartaogravado.substring(182,194))
    || RFleitura.substring(1,13).equals(cartaogravado.substring(196,208))
    || RFleitura.substring(1,13).equals(cartaogravado.substring(210,222))
    || RFleitura.substring(1,13).equals(cartaogravado.substring(224,236)) 
    || RFleitura.substring(1,13).equals(cartaogravado.substring(238,250))
    || RFleitura.substring(1,13).equals(cartaogravado.substring(252,264))
    || RFleitura.substring(1,13).equals(cartaogravado.substring(266,278))
    || RFleitura.substring(1,13).equals(cartaogravado.substring(280,292))
    || RFleitura.substring(1,13).equals(cartaogravado.substring(294,306))
    || RFleitura.substring(1,13).equals(cartaogravado.substring(308,320))
    || RFleitura.substring(1,13).equals(cartaogravado.substring(322,334))
    || RFleitura.substring(1,13).equals(cartaogravado.substring(336,348))
    || RFleitura.substring(1,13).equals(cartaogravado.substring(350,362))
    || RFleitura.substring(1,13).equals(cartaogravado.substring(364,376))
    || RFleitura.substring(1,13).equals(cartaogravado.substring(378,390))
    || RFleitura.substring(1,13).equals(cartaogravado.substring(392,404))
    || RFleitura.substring(1,13).equals(cartaogravado.substring(406,418))
    || RFleitura.substring(1,13).equals(cartaogravado.substring(420,432))
    || RFleitura.substring(1,13).equals(cartaogravado.substring(434,446))
    || RFleitura.substring(1,13).equals(cartaogravado.substring(448,460))
    || RFleitura.substring(1,13).equals(cartaogravado.substring(462,474))
    || RFleitura.substring(1,13).equals(cartaogravado.substring(476,488))
    || RFleitura.substring(1,13).equals(cartaogravado.substring(490,502))
    || RFleitura.substring(1,13).equals(cartaogravado.substring(504,516))
    || RFleitura.substring(1,13).equals(cartaogravado.substring(518,530))
    || RFleitura.substring(1,13).equals(cartaogravado.substring(532,544)) 
    || RFleitura.substring(1,13).equals(cartaogravado.substring(546,558))
    || RFleitura.substring(1,13).equals(cartaogravado.substring(560,572))
    || RFleitura.substring(1,13).equals(cartaogravado.substring(574,586))
    || RFleitura.substring(1,13).equals(cartaogravado.substring(588,600))
    || RFleitura.substring(1,13).equals(cartaogravado.substring(602,614))
    || RFleitura.substring(1,13).equals(cartaogravado.substring(616,628))
    || RFleitura.substring(1,13).equals(cartaogravado.substring(630,642))
    || RFleitura.substring(1,13).equals(cartaogravado.substring(644,656))
    || RFleitura.substring(1,13).equals(cartaogravado.substring(658,670))
    || RFleitura.substring(1,13).equals(cartaogravado.substring(672,684))
    || RFleitura.substring(1,13).equals(cartaogravado.substring(686,698))
    //Para aumentar o numero de comparações: cartaogravado.substring(487 + 18,481 + 18)
   ){
    Serial.println("Usuario Valido!");
    Serial.println("Acesso Liberado!");
    //Cargas();
  }//Fecha if -----------------------------------------------------------------
  else{
    Serial.println("Acesso Negado");
    Serial.println("Fale com a Administracao");
    //Recadastro();
  }
}
void Cargas(){
return;
}
void AbrirSD(){
//Abrir arquivo SD -------------------------------------------------------- 
  arquivo=SD.open("Cadastro.txt");
  if(arquivo){
    while(arquivo.available()){
      leicartao = arquivo.read();                    //leicartao é char
      cartaogravado += leicartao;                    //cartaogravado String
    }//fecha while Sd open---------------------------------------------------
    arquivo.close();
  }//Fecha if arquivo--------------------------------------------------------
  else{
    //Serial.println("Erro ao abrir o arquivo de leitura");
  }
}
void Passatag(){
  //Inicio das leituras dos cartoes ou tags-------------------------------------
  while(RFID.available()){
    for(char j=0;j<=15;j++){
      valorlido[j]= RFID.read();                         //Valolido é char
      delay(10);
    }
    if (sizeof(valorlido)>=15){                          //Verifica o tamanho de valorlido
     Serial.print("Numero do Cartao: ");
      for(char j=1;j<=14;j++){                           //Faz a leitura do array valor lido sem lixo
        Serial.print(valorlido[j]);                      //A posição [0] e [15] são espaços em branco
        RFleitura=valorlido; 
                                   //Armazena na Strnig RFleitura para posterior comparação com cartões guardados no SD     
      }       
        AbrirSD();
        Verificar();
    }//Fecha SizaOf-------------------------------------------------------------
  }//Fecha primeiro While-------------------------------------------------------
}

void loop(){ 
  if(ok){
    Passatag();
    Menu(); 
  }//Fecha Inicio_ok
}//Fecha loop-------------------------------------------------------------------

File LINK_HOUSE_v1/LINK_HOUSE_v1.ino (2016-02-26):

/*
  Automação Residencial
  Project: Homefi_AX
  Author: Yuri Lima & Reginaldo Barros
  Date: 27/10/2015 - 22:50
  "GVT-Yuri Lima"
  48291110
*/
#ifdef ESP8266
extern "C" {
#include "user_interface.h"
}
#endif
#ifdef arduino
extern "C" {
#include "avr/io.h"
}
#endif
//OBS Modulo com duas GPIOS protocolo diferenciado Pinagem diferente
//"$1#1#######"
//=======================================================
//Bibliotecas
//#include <avr / io.h>
//#include <util/delay.h>
#include <ESP8266WiFi.h>
#include <WiFiClient.h>
#include <ESP8266WebServer.h>
#include <ESP8266mDNS.h>
#include <DHT11.h>
//=======================================================
//DEBUG
#define DEBUG 1
//=======================================================
//Protocolo de Comunicação
#define T_ACTION pc_Request.charAt(0) //Tipo de Ação?
#define N_ACTION Serial.print("#");//Sem ação
//Acesso Wifi
//Usuario da internet Station
const char* ssid = "GVT-Yuri Lima";//Usuario da internet
const char* pswd = "48291110";//Senha do Wifi
//Usuario da internet Acess Point
//const char PSWD[] = "48291110";
//=======================================================
////Acesso wifi modulo ESP
//#define MY_SSID   "LinkHouse"
//#define MY_PASSWD "78945612"
//=======================================================
//Objeto da classe
WiFiServer server(8082);//Porta de Comunicação
//=======================================================
//Variaveis
#define CARGA 12
#define DHTPIN 16
//#define MANUAL 14
DHT11 dht11(DHTPIN);
unsigned long previousMillis = 0;
const long interval = 500;
unsigned long previousMillis2 = 0;
const long interval2 = 5000;//Temperatura
int status = WL_IDLE_STATUS;
int h, t;
volatile bool flag1, flag2;
volatile int MANUAL = 14;
String MAC; 
//=======================================================
//Prototipo das funções
#if DEBUG
void printWifiStatus();
#endif
void ManualChange();
//==================================================================================
void setup() {
  //DDRB=0b00000000;
  pinMode(MANUAL, INPUT);
  pinMode(CARGA, OUTPUT);
  attachInterrupt(digitalPinToInterrupt (MANUAL), ManualChange, CHANGE);
#if DEBUG
  Serial.begin(115200);
#endif
  //delay(10);
  //WiFi.mode(WIFI_AP_STA); //AP,STA,AP_STA,OFF Colocar em modo AP e Station
  // WiFi.softAP("LinkHouse", "78945612"); //na lib do Arduino eh diferente; WiFi.begin(S,P)
  WiFi.begin(ssid, pswd);
  while (WiFi.status() != WL_CONNECTED) {
    delay(100);
    Serial.print(F("."));
  }
  //===========================================================================================================
  Serial.println("");
  // Start the server
  server.begin(); //Server iniciado
  // Print the IP address
#if DEBUG
  WiFi.printDiag(Serial);
  //Serial.print(F("IP_MOD_ESP: "));
  //Serial.println(WiFi.localIP());
  Serial.print(F("IP AP: "));
  Serial.println(WiFi.softAPIP());
  Serial.print(F("MAC_MOD_ESP: "));
  MAC = WiFi.macAddress();
  Serial.println(MAC);
  Serial.print(F("Nome do modulo - hostname: "));
  Serial.println(wifi_station_get_hostname());
  printWifiStatus();
#endif
}

void loop() {
  //===========================================================================================================
  unsigned long currentMillis = millis();
  if (currentMillis - previousMillis >= interval) {
    // save the last time you read the sensor
    previousMillis = currentMillis;
    if (!flag1)   {
      digitalWrite(CARGA, !digitalRead(CARGA));
      flag1 = true;
    }
  }
  // Check if a client has connected
  //===========================================================================================================
  WiFiClient client = server.available();
  if (!client) {
    return;
  }
  // Wait until the client sends some data
#if DEBUG
  Serial.println(F("Nova Requisicao"));
#endif
  //===========================================================================================================
  while (!client.available()) {
    delay(1);
  }
  //===========================================================================================================
  // Read os dados de protocolo enviado
  String pc_Request = client.readStringUntil('\r');
#if DEBUG
  Serial.print(F("Protocolo: "));
  Serial.println(pc_Request);
#endif
  client.flush();//Limpa buffer
  /*client.println(F("HTTP/1.1 200 OK"));
    client.println(F("Content-Type: text/html"));
    client.println();
    client.println(F("<HTML>"));
    client.println(F("<head>"));
    client.println(F("<title> Link House </title>"));//Titulo da aba
    client.println(F("</head>"));
    client.println(F("<body>"));
    client.println(F("<h2>Configurar Rede Wifi</h2>"));
    client.println(F("<form method='get'>"));
    client.println(F("Nome da rede: <input type='text' name='ssid'>"));
    client.println(F("<br>"));
    client.println(F("Senha da rede: <input type='password' name='pswd'>"));
    client.println(F("<br>"));
    client.println(F("<input type='submit' value='Salvar'>"));
    client.println(F("</form>"));
    client.println(F("</body>"));
    client.println(F("</HTML>"));
    delay(1);*/
  //===========================================================================================================
  if (T_ACTION == '$') {
#if DEBUG
    Serial.println(F("Acionamento de Carga."));
#endif
    if (pc_Request.charAt(2) == '1')digitalWrite(CARGA, !digitalRead(CARGA));
    else if (pc_Request.charAt(2) == '0') digitalWrite(CARGA, !digitalRead(CARGA));
  }
  //===========================================================================================================
  if (T_ACTION == '*') {

#if DEBUG
    Serial.println(F("Retorno de Status."));
#endif
    pc_Request = pc_Request + digitalRead(CARGA);
    pc_Request = pc_Request + "########";
    pc_Request = pc_Request + MAC;
    //pc_Request = '@';
    //pc_Request = pc_Request + t;
    //pc_Request = pc_Request + h;
#if DEBUG
    Serial.println(pc_Request);
#endif
    client.println(pc_Request);
  }
  //===========================================================================================================
  if (T_ACTION == '&') {
#if DEBUG
    Serial.println(F("Teste de Comunicacao."));
#endif
    client.println('&');
  }
  //===========================================================================================================
#if DEBUG
  Serial.println(F("Client disonnected"));
  Serial.println("");
#endif

}
#if DEBUG
void printWifiStatus() {
  // print the SSID of the network you're attached to:
  Serial.print(F("Nome da rede - SSID: "));
  Serial.println(WiFi.SSID());

  // print your WiFi shield's IP address:
  IPAddress ip = WiFi.localIP();
  Serial.print(F("Endereco de IP: "));
  Serial.println(ip);

  // print the received signal strength:
  long rssi = WiFi.RSSI();
  Serial.print(F("Intensidade do Sinal (RSSI):"));
  Serial.print(rssi);
  Serial.println(F(" dBm"));
}
#endif
void ManualChange() {
  flag1 = false;
}

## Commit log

2014-11-26 Add more Var of Sensor
2014-11-29 Simple Timer
    Projeto em produção
2014-11-29 Simple Timer.
2014-12-20 Projeto de Automação Residencial
    Estamos evoluindo no projeto RF_id_Link_House_8 usando o modulo ID12. Já foi criado várias funcionalidades como criação de arquivo em SD_CARD, cadastro de tags no SD, excluir arquivo do SD, desabilit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
2014-12-31 Refatorado! Inclusao de cadastro do nome de Usuarios com a Data

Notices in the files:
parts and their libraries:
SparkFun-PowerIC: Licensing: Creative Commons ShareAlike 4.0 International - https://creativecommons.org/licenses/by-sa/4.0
